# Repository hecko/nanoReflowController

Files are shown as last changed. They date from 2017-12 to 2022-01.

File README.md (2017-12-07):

Reflow Oven Controller
====================

**News**

* Forked from 0xPIT & uploaded the code after a lot of restructuration
* Board design has also changed

**Arduino-based reflow oven controller with:**
* [PID] loop control
* [Wave Packet] control for AC output
* graphic TFT LC-Display, drawing the temperature curves
  * using a 5v compatible 1.8" of 1.44" TFT SPI display with ST7735 controller
* solely controlled using a cheap rotary encoder and its single button
* uses a MAX6675 module as interface to a K type thermocouple
* stores up to 30 temperature profiles in EEPROM
* configurable PID-parameters
* simple, small hardware to drive loads up to 600V and up to 2A without heatsink
* powered throuhg one of three options: 12v RAW pin, 5v pin or 5v USB
* optional 12v fan control (not yet implemented in the code)
* *Please Note*: Requires Arduino IDE 1.5.x or newer

(c) 2017 David Sanz Kirbis
(c) 2014 Karl Pitrich <karl@pitrich.com>
in part based on a project (c) 2013 Ed Simmons <ed@estechnical.co.uk>

## Warning: This project operates with possibly lethal mains voltage. If you are unsure what to do, don't do it and get help from an experienced tinkerer with professional training.

**Minimal build**

BoardPic1 | BoardPic2
------------ | -------------

**Completely populated**

Complete1 | Complete2 | Complete3
------------ | ------------ | -------------

**Enclosed and mounted on halogen floodlight**

(more info: [Halogen Floodlight SMT reflow])

Floodlight
--------------

<!---
**Post action shot**

![CycleWithOverflow] | ![Warning]
------------ | -------------

Introduction
====================

This Reflow Oven Controller relies on an [Arduino Nano] easily obtainable on eb*y for less than $10, plus my custom shield, which is actually more like a motherboard.

As I believe it is not wise to have a mess of wiring and tiny breakout-boards for operating mains powered equipment, I've decided to design custom board with easily obtainable components.

The hardware can be found in the [folder hardware], including the Eagle schematics and PCB layout files. It should fit the freemium version of Eagle. Here are preview images:

![PCB][ImgPCB]
![Schematic][ImgSCH]

The board contains the [Arduino Nano], very simple [Zero crossing] detection circuit, used to align control logic to mains frequency, two [MAX31855] thermocouple-to-digital converters and two [Sharp S202S01] PCB-mount solid state relays, mounted on cheap [Fischer SK409 50,8] heat sinks. The current software uses only one of the thermocouples, so you need to populate one IC only. If you're lucky, you can get free samples of the MAX31855 from Maxim.

The software uses [PID] control of the heater and fan output for improved temperature stability. The heater AC load is controlled using [Wave Packet] control in order to minimize RF interference and load on the relay. For the fan motor, [Phase Fired] control has been implemented.

Please note that all important timings are *based on the mains frequency*, so the circuit will **not work** properly without mains connection.

But for testing, I've added an additional timer to simulate the zero-crossings, in order to run the software without being connected to mains. The software should work in 50 and 60Hz mains, the 60Hz version is not tested, though.

Errata and construction infos
========

Issue | Notes
------------ | -------------

Screenshots and usage information
========

Image | Information
------------ | -------------
![CycleWithOverflow] | *Display after a cylcle has been completed. The blue line is the setpoint, the red line the actual temperature measured by the thermocouple. Note that the graph wraps around automatically. 'Sp' is the current setpoint calculated by the PID loop. In the lower line there are: Current heater and fan outputs, both in percent, and the current temperature rise or drop rate in °C per second. The graph will draw orientation lines every 50°C up to the peak temperature set in the selected profile.*
![MenuDefault] | *The main menu can be navigated by rotating the encoder (sic!). Clicking enters the menu item, or navigates to the submenu. Doubleclick moves up or back or exits the menu item.*
![FanSpeedEdit] | *To edit a setting, click once to enter edit mode (red cursor), then rotate to change the value, click again to save. Doubleclick will exit without saving.*
![MenuEditProfile] | -
![ProfileSettings] | *Typical solder profile settings...*
![ProfileSettingsEdit] | *These parameters can be easily edited using the encoder as described above.*
![MenuLoadProfile] | *Up to 30 Profiles can be loaded and saved. You have to do this manually, so that you can have 'save-as' functionality without overwriting existing profiles.*
![PIDValues] | *Current pid values for my 1300W 20$ toaster oven.*
![PIDValuesEdit] | *Editing is simple, like above. Note that, unlike with the profile settings, the PID values will be automatically stored to EEPROM when you exit the submenu by doubleclicking.*
--->

Obtaining the source code
====================

Get the code using `git`.

	git clone https://github.com/hecko/nanoReflowController.git

or [download a Snapshot].

I've added some libraries I've used as submodules to the git repositroy, so it is important that, after cloning this repository, you do 

    git submodule update --init

to fetch all involved libraries. (See: [Submodule Cheat Sheet])

Installation
====================

Of course, you need to have the Arduino IDE installed. I've worked with version 1.5.x only and I will not support older versions. Get it from the [Arduino Download] page or upgrade you current Arduino setup.

There as several dependencies you need to install. 

If you are unfamiliar with Arduino Libraries, please read [the library guide].
Basically, each library needs to be liked or copied into your Arduino library folder.

<!---
My code uses [TimerOne] for basic timing, for the 1.8" TFT I've used [Adafruit_ST7735], which requires [Adafruit_GFX]. I **strongly suggest** to use my **modified version** of [Adafruit_ST7735-pit], as it **performs much better**, but requires you to use SPI, which my board does anyway.

For the user interface you require my own [Menu] and [ClickEncoder] libraries, which are included as submodules.

All other libraries need to be downloaded and installed.

After you've installed all libraries, open the Arduino IDE, open the ReflowController.pde sketch (using File->Open).

Select the right hardware from the Tools->Board menu.

Compile the firmware (Sketch->Verify) to test everything is installed correctly. If something's wrong, feel free to post an issue here on github, I will look into it.

Now, choose the correct serial port from Tools->Serial Port and then upload the code.
*Remember* that a standard compile will get stuck at "Calibrating..." without proper mains connection, so that zero crossing interrupts can occur.

I could not fit PID Autotuning into the limited space of the Arduino in addition the normal code. So if you want to try to autotune you PID Loop, install the [PID_AutoTune] Library, `#define PIDTUNE 1` in the .ino file, then recompile and download do the Arduino.

As all timing relies on Zero Crossing detection, you need to `#define FAKE_HW 1` and install [TimerThree] when you want to run without actual hardware *and/or* without mains connection.

Things to note
====================

* The [MAX31855] does not like the thermocouple being grounded; It must be isolated from ground or earth.
* The PID Loop must be tuned individually for each oven. It will *not* work out of the box. 
* [PID Autotune] is not very useful, as it seems to be able to tune only to keep a specific temperature value, which is not what we do in a reflow oven. Also, at least my oven seems to be very non-linear when heating up.
* When rewiring inside your oven, use only wiring that can withstand high temperatures. I use silicone coated lace.
* Do not solder wiring inside you oven, the temperature might desolder you joints. **Crimp everything.**
* Use proper earth ground connection for your ovens chassis.

Ideas and todo
====================
* Optimize code size so that more features can fit
* Clamp values for parameters to reasonalbe ranges
* Add scrollbar (sample implementation in the demo for [Menu]
* Separate PID configuration for each process step
* try to make the display faster, it is very slow
* Named profiles
* Rewrite [Menu] so that is uses callback objects instead of spaghetti-callbacks
--->

Licensing
====================
```
The MIT License (MIT)

Copyright (c) 2017 David Sanz Kirbis
All rights reserved.

Permission is hereby granted, free of charge, to any person obtaining a copy
of this software and associated documentation files (the "Software"), to deal
in the Software without restriction, including without limitation the rights
to use, copy, modify, merge, publish, distribute, sublicense, and/or sell
copies of the Software, and to permit persons to whom the Software is
furnished to do so, subject to the following conditions:

The above copyright notice and this permission notice shall be included in
all copies or substantial portions of the Software.

THE SOFTWARE IS PROVIDED "AS IS", WITHOUT WARRANTY OF ANY KIND, EXPRESS OR
IMPLIED, INCLUDING BUT NOT LIMITED TO THE WARRANTIES OF MERCHANTABILITY,
FITNESS FOR A PARTICULAR PURPOSE AND NONINFRINGEMENT. IN NO EVENT SHALL THE
AUTHORS OR COPYRIGHT HOLDERS BE LIABLE FOR ANY CLAIM, DAMAGES OR OTHER
LIABILITY, WHETHER IN AN ACTION OF CONTRACT, TORT OR OTHERWISE, ARISING FROM,
OUT OF OR IN CONNECTION WITH THE SOFTWARE OR THE USE OR OTHER DEALINGS IN
THE SOFTWARE.
```

[PID Autotune]:https://github.com/br3ttb/Arduino-PID-AutoTune-Library
[Submodule Cheat Sheet]:http://blog.jacius.info/git-submodule-cheat-sheet/
[ESTechnical]:http://www.estechnical.co.uk
[Arduino Download]:http://arduino.cc/en/Main/Software
[folder hardware]:https://github.com/dasaki/nanoReflowController/tree/master/hardware
[download a Snapshot]:https://github.com/dasaki/nanoReflowController/archive/master.zip
[the library guide]:http://arduino.cc/en/Guide/Libraries
[PID]:http://en.wikipedia.org/wiki/PID_controller
[Wave Packet]:http://de.wikipedia.org/wiki/Schwingungspaketsteuerung
[Phase Fired]:http://en.wikipedia.org/wiki/Phase-fired_controllers 
[Adafruit 1.8" TFT]:http://www.adafruit.com/products/358
[MAX31855]:http://www.maximintegrated.com/en/products/analog/sensors-and-sensor-interface/MAX31855.html
[Fischer SK409 50,8]:http://www.pollin.de/shop/dt/NzE5OTY1OTk-
[Sharp S202S01]:http://sharp-world.com/products/device/lineup/data/pdf/datasheet/s102s01_e.pdf
[Zero crossing]:http://en.wikipedia.org/wiki/Zero_crossing
[TimerOne]:http://playground.arduino.cc/Code/Timer1
[TimerThree]:http://playground.arduino.cc/Code/Timer1
[Adafruit_ST7735]:https://github.com/adafruit/Adafruit-ST7735-Library
[Adafruit_GFX]:https://github.com/adafruit/Adafruit-GFX-Library
[Adafruit_ST7735-pit]:https://github.com/0xPIT/Adafruit-ST7735-Library
[Menu]:https://github.com/0xPIT/menu
[ClickEncoder]:https://github.com/0xPIT/encoder
[Arduino Nano]:https://store.arduino.cc/arduino-nano

[CycleWithOverflow]:https://raw.githubusercontent.com/0xPIT/reflowOvenController/master/images/CycleWithOverflow.jpg
[FanSpeedEdit]:https://raw.githubusercontent.com/0xPIT/reflowOvenController/master/images/FanSpeedEdit.jpg
[MenuDefault]:https://raw.githubusercontent.com/0xPIT/reflowOvenController/master/images/Menu.jpg
[MenuLoadProfile]:https://raw.githubusercontent.com/0xPIT/reflowOvenController/master/images/MenuLoadProfile.jpg
[MenuEditProfile]:https://raw.githubusercontent.com/0xPIT/reflowOvenController/master/images/MenuEditProfile.jpg
[PIDValuesEdit]:https://raw.githubusercontent.com/0xPIT/reflowOvenController/master/images/PIDValuesEdit.jpg
[ProfileSettings]:https://raw.githubusercontent.com/0xPIT/reflowOvenController/master/images/ProfileSettings.jpg
[PIDValues]:https://raw.githubusercontent.com/0xPIT/reflowOvenController/master/images/PIDValues.jpg
[ProfileSettingsEdit]:https://raw.githubusercontent.com/0xPIT/reflowOvenController/master/images/ProfileSettingsEdit.jpg

[Warning]:http://www.proshieldsafetysigns.co.uk/signs/59793_signs.jpg
[ImgPCB]:https://raw.githubusercontent.com/0xPIT/reflowOvenController/master/hardware/v0.2.brd.preview.png
[ImgSCH]:https://raw.githubusercontent.com/0xPIT/reflowOvenController/master/hardware/v0.2.sch.preview.png

[ImgMissingTrace]:https://raw.githubusercontent.com/0xPIT/reflowOvenController/master/images/MissingTrace.jpg
[BoardPic1]:https://raw.githubusercontent.com/dasaki/nanoReflowController/master/images/v1_0_Board_picture_top.jpg
[BoardPic2]:https://raw.githubusercontent.com/dasaki/nanoReflowController/master/images/v1_0_Board_picture_bottom.jpg
[Complete1]:https://raw.githubusercontent.com/dasaki/nanoReflowController/master/images/v1_0_Board_3d_01.png
[Complete2]:https://raw.githubusercontent.com/dasaki/nanoReflowController/master/images/v1_0_Board_3d_02.png
[Complete3]:https://raw.githubusercontent.com/dasaki/nanoReflowController/master/images/v1_0_Board_3d_03.png
[Floodlight]:https://raw.githubusercontent.com/dasaki/nanoReflowController/master/images/v1_0_floodlight_reflow.jpg
[Halogen Floodlight SMT reflow]:http://therandomlab.blogspot.com.es/2017/07/halogen-floodlight-smt-reflow.html

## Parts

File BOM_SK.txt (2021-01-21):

Reflektor:
  * https://www.hagard.sk/katalog-produktov/svietidla-zdroje-objimky-transformatory-1/svietidla-reflektory/reflektor-halogenovy-6107-500w-r7s-118mm-230v-ip44-cierna.html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 / EAN: 8590849061079 / Ecoplanet / Hagard kod: SRE000000154

Kapton paska:
  * P3D0107PT / elecrow

Alobal

6mm (vonkajsi priemer / 4mm vnutorny) teflonova trubka
  * gumex.sk / 0165060000000209
  * http://www.sterimob.sk/e-4241-ptfe-trubka-teflon-64mm
  * SOS: 26386

Elektronicke komponenty:
  * poistka: 1271687 / farnell
  * encoder: SMEC11EN / elecrow
  * display: https://techfun.sk/produkt/segmentovy-display-tm1637
  * K-type thermocouple: SPM28130K / elecrow / https://techfun.sk/produkt/k-type-termoclanok-kabel-1-meter/
  * Arduino Nano klon: MCA03328A / elecrow

Vyroba dosiek: Elecrow / SPF11010S

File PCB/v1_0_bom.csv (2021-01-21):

DESIGNATORS | VALUE | VALUE_NOTE | VALUE_EX | LIBREF | FOOTPRINT | FARNELL | SOS | MOUSER | TME | DIGIKEY | FILEPATH
ARDUINO_NANO_(5V)1 | arduino_nano_header |  |  | arduino-headers:arduino_nano_header | Module:Arduino_Nano |  |  |  |  |  | ./nanoReflow_v1.0_rev3//arduino_nano_reflow_TRIAC_v1_0.sch
C2 C3 | 100n |  |  | Device:C | Capacitor_SMD:C_0805_2012Metric |  |  |  |  |  | ./nanoReflow_v1.0_rev3//arduino_nano_reflow_TRIAC_v1_0.sch
R2 R1 | 47k 0.6w |  |  | Device:R | Resistor_THT:R_Axial_DIN0207_L6.3mm_D2.5mm_P7.62mm_Horizontal |  |  |  |  |  | ./nanoReflow_v1.0_rev3//arduino_nano_reflow_TRIAC_v1_0.sch
R7 | 100K |  |  | Device:R | Resistor_SMD:R_1210_3225Metric |  |  |  |  |  | ./nanoReflow_v1.0_rev3//arduino_nano_reflow_TRIAC_v1_0.sch
J2 | HEATER |  |  | arduino_nano_reflow_TRIAC_v1_0-rescue:Screw_Terminal_1x02 | TerminalBlock_Phoenix:TerminalBlock_Phoenix_MKDS-1;5-2_1x02_P5.00mm_Horizontal |  |  |  |  |  | ./nanoReflow_v1.0_rev3//arduino_nano_reflow_TRIAC_v1_0.sch
J3 | DC IN 12V |  |  | arduino_nano_reflow_TRIAC_v1_0-rescue:Screw_Terminal_1x02 | TerminalBlock_Phoenix:TerminalBlock_Phoenix_MKDS-1;5-2_1x02_P5.00mm_Horizontal |  |  |  |  |  | ./nanoReflow_v1.0_rev3//arduino_nano_reflow_TRIAC_v1_0.sch
J1 | AC IN 220v |  |  | arduino_nano_reflow_TRIAC_v1_0-rescue:Screw_Terminal_1x02 | TerminalBlock_Phoenix:TerminalBlock_Phoenix_MKDS-1;5-2_1x02_P5.00mm_Horizontal |  |  |  |  |  | ./nanoReflow_v1.0_rev3//arduino_nano_reflow_TRIAC_v1_0.sch
Q1 | IRF540N |  |  | Transistor_FET:IRF540N | Package_TO_SOT_THT:TO-220-3_Vertical |  |  |  |  |  | ./nanoReflow_v1.0_rev3//arduino_nano_reflow_TRIAC_v1_0.sch
D1 | 1N4007 |  |  | Device:D_Small | Diode_THT:D_A-405_P5.08mm_Vertical_AnodeUp |  |  |  |  |  | ./nanoReflow_v1.0_rev3//arduino_nano_reflow_TRIAC_v1_0.sch
J9 | MAX6675 |  |  | Connector_Generic:Conn_01x05 | Connector_PinHeader_2.54mm:PinHeader_1x05_P2.54mm_Vertical |  |  |  |  |  | ./nanoReflow_v1.0_rev3//arduino_nano_reflow_TRIAC_v1_0.sch
BZ1 | Buzzer with generator |  |  | Device:Buzzer | Buzzer_Beeper:Buzzer_12x9.5RM7.6 |  |  |  |  |  | ./nanoReflow_v1.0_rev3//arduino_nano_reflow_TRIAC_v1_0.sch
R6 | 4K7 |  |  | Device:R | Resistor_SMD:R_1210_3225Metric |  |  |  |  |  | ./nanoReflow_v1.0_rev3//arduino_nano_reflow_TRIAC_v1_0.sch
JP1 | VIN enabler |  |  | Jumper:Jumper_2_Open | Pin_Headers:Pin_Header_Straight_1x02_Pitch2.54mm |  |  |  |  |  | ./nanoReflow_v1.0_rev3//arduino_nano_reflow_TRIAC_v1_0.sch
R5 | 1k |  |  | Device:R | Resistor_SMD:R_0603_1608Metric |  |  |  |  |  | ./nanoReflow_v1.0_rev3//arduino_nano_reflow_TRIAC_v1_0.sch
R3 | 2.4k |  |  | Device:R | Resistor_THT:R_Axial_DIN0207_L6.3mm_D2.5mm_P7.62mm_Horizontal |  |  |  |  |  | ./nanoReflow_v1.0_rev3//arduino_nano_reflow_TRIAC_v1_0.sch
J12 J13 J14 | MOUNTING_HOLE |  |  | arduino_nano_reflow_TRIAC_v1_0-rescue:CONN_01X01 | MountingHole:MountingHole_3.2mm_M3_Pad |  |  |  |  |  | ./nanoReflow_v1.0_rev3//arduino_nano_reflow_TRIAC_v1_0.sch
U1 | MOC3020M |  |  | Relay_SolidState:MOC3020M | Package_DIP:DIP-6_W7.62mm |  |  |  |  |  | ./nanoReflow_v1.0_rev3//arduino_nano_reflow_TRIAC_v1_0.sch
R4 | 180R |  |  | Device:R | Resistor_THT:R_Axial_DIN0207_L6.3mm_D2.5mm_P7.62mm_Horizontal |  |  |  |  |  | ./nanoReflow_v1.0_rev3//arduino_nano_reflow_TRIAC_v1_0.sch
C1 | 10n |  |  | Device:C | Capacitor_THT:C_Disc_D4.3mm_W1.9mm_P5.00mm |  |  |  |  |  | ./nanoReflow_v1.0_rev3//arduino_nano_reflow_TRIAC_v1_0.sch
J11 | CONN_01X03 |  |  | arduino_nano_reflow_TRIAC_v1_0-rescue:CONN_01X03 | Pin_Headers:Pin_Header_Straight_1x03_Pitch2.54mm |  |  |  |  |  | ./nanoReflow_v1.0_rev3//arduino_nano_reflow_TRIAC_v1_0.sch
KK1 | TRIAC HEATSINK |  |  | SK_09_20_SA_TO_220:SK_09_20_SA_TO_220 | local_libraries:TO_220_heatsink |  |  |  |  |  | ./nanoReflow_v1.0_rev3//arduino_nano_reflow_TRIAC_v1_0.sch
OK1 | H11AA1 |  |  | Isolator:H11AA1 | Package_DIP:DIP-6_W7.62mm |  |  |  |  |  | ./nanoReflow_v1.0_rev3//arduino_nano_reflow_TRIAC_v1_0.sch
TRIAC1 | BT137 |  |  | Device:Q_TRIAC_A1A2G | Package_TO_SOT_THT:TO-220-3_Vertical |  |  |  |  |  | ./nanoReflow_v1.0_rev3//arduino_nano_reflow_TRIAC_v1_0.sch
F1 | Fuse |  |  | Device:Fuse | Fuse_Holders_and_Fuses:Fuseholder5x20_horiz_open_inline_Type-I |  |  |  |  |  | ./nanoReflow_v1.0_rev3//arduino_nano_reflow_TRIAC_v1_0.sch
J4 | 12V FAN |  |  | arduino_nano_reflow_TRIAC_v1_0-rescue:Screw_Terminal_1x02 | TerminalBlock_Phoenix:TerminalBlock_Phoenix_MKDS-1;5-2_1x02_P5.00mm_Horizontal |  |  |  |  |  | ./nanoReflow_v1.0_rev3//arduino_nano_reflow_TRIAC_v1_0.sch
J5 | CONN_01X04 |  |  | Connector_Generic:Conn_01x04 | Connector_PinHeader_2.54mm:PinHeader_1x04_P2.54mm_Vertical |  |  |  |  |  | ./nanoReflow_v1.0_rev3//arduino_nano_reflow_TRIAC_v1_0.sch
J6 | K-thermocouple |  |  | arduino_nano_reflow_TRIAC_v1_0-rescue:Screw_Terminal_1x02 | TerminalBlock_Phoenix:TerminalBlock_Phoenix_MKDS-1;5-2_1x02_P5.00mm_Horizontal |  |  |  |  |  | ./nanoReflow_v1.0_rev3//arduino_nano_reflow_TRIAC_v1_0.sch
U2 | MAX6675 |  |  | max6675:MAX6675 | Package_SO:SO-8_3.9x4.9mm_P1.27mm |  |  |  |  |  | ./nanoReflow_v1.0_rev3//arduino_nano_reflow_TRIAC_v1_0.sch

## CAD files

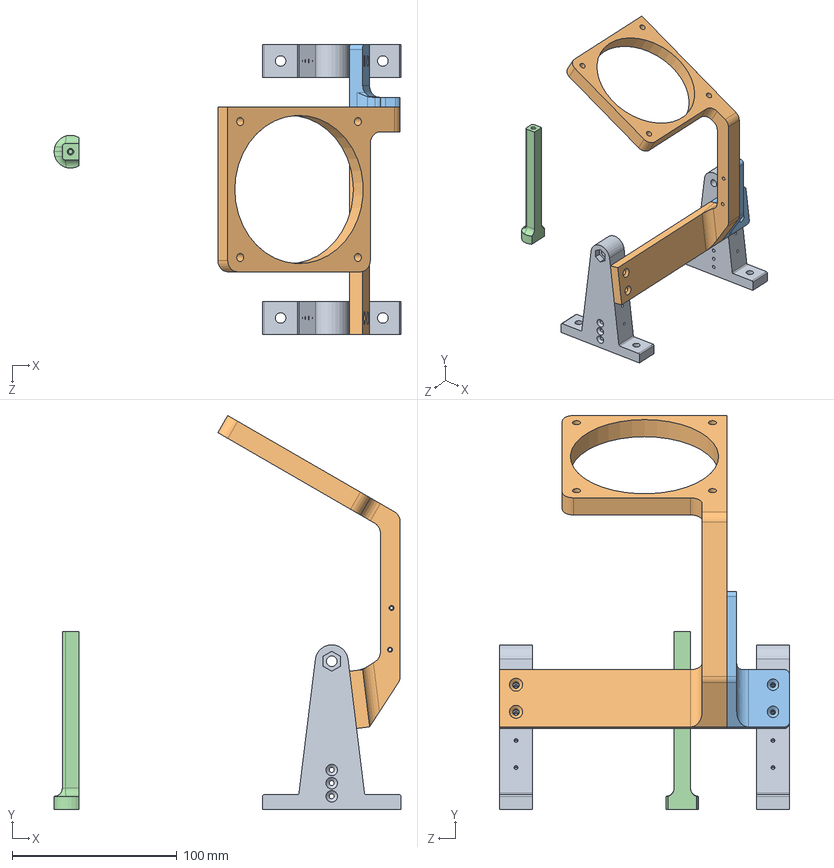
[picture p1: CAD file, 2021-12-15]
CAD/zostava_halogenka.SLDASM
210.6 x 239.2 x 176.0 mm
noha x 2
podpora_pred

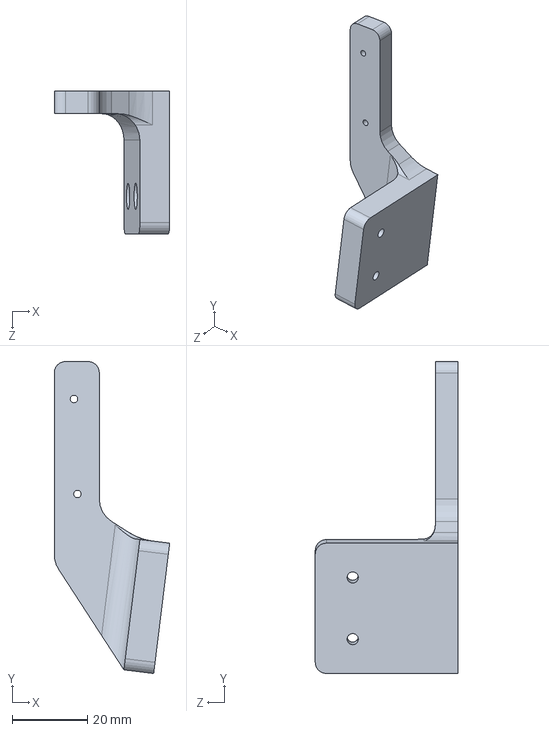
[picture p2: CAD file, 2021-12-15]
CAD/Part2.sldprt
30.8 x 83.1 x 38.0 mm

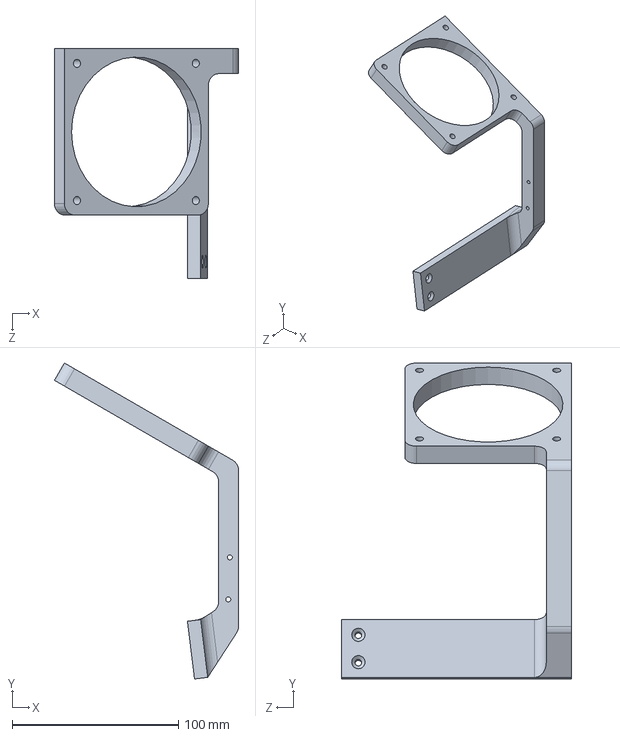
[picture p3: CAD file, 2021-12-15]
CAD/Part1.sldprt
110.7 x 190.0 x 138.0 mm

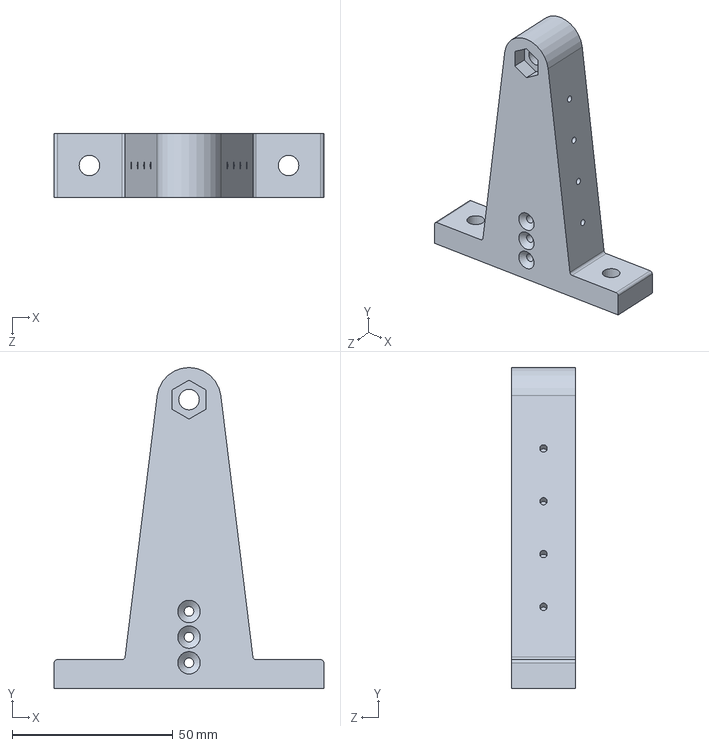
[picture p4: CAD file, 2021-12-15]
CAD/noha.SLDPRT
84.0 x 100.0 x 20.0 mm

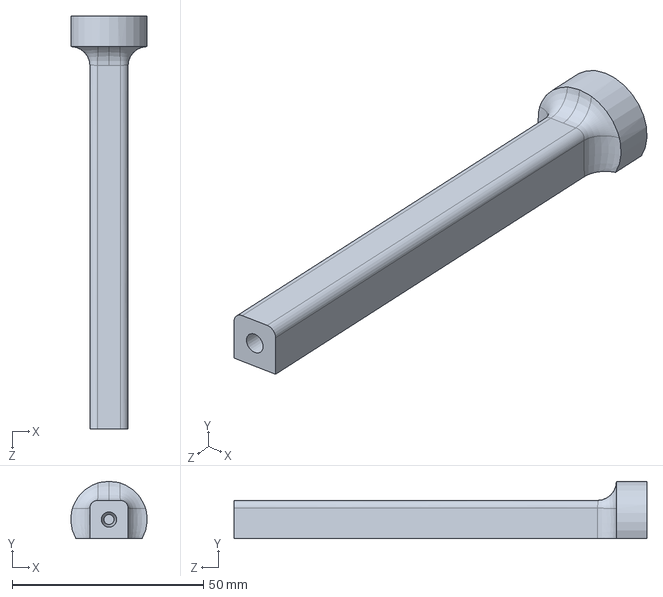
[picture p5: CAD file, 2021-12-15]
CAD/podpora_pred.SLDPRT
20.0 x 15.0 x 108.0 mm

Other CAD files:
CAD/podpora_pred.STL

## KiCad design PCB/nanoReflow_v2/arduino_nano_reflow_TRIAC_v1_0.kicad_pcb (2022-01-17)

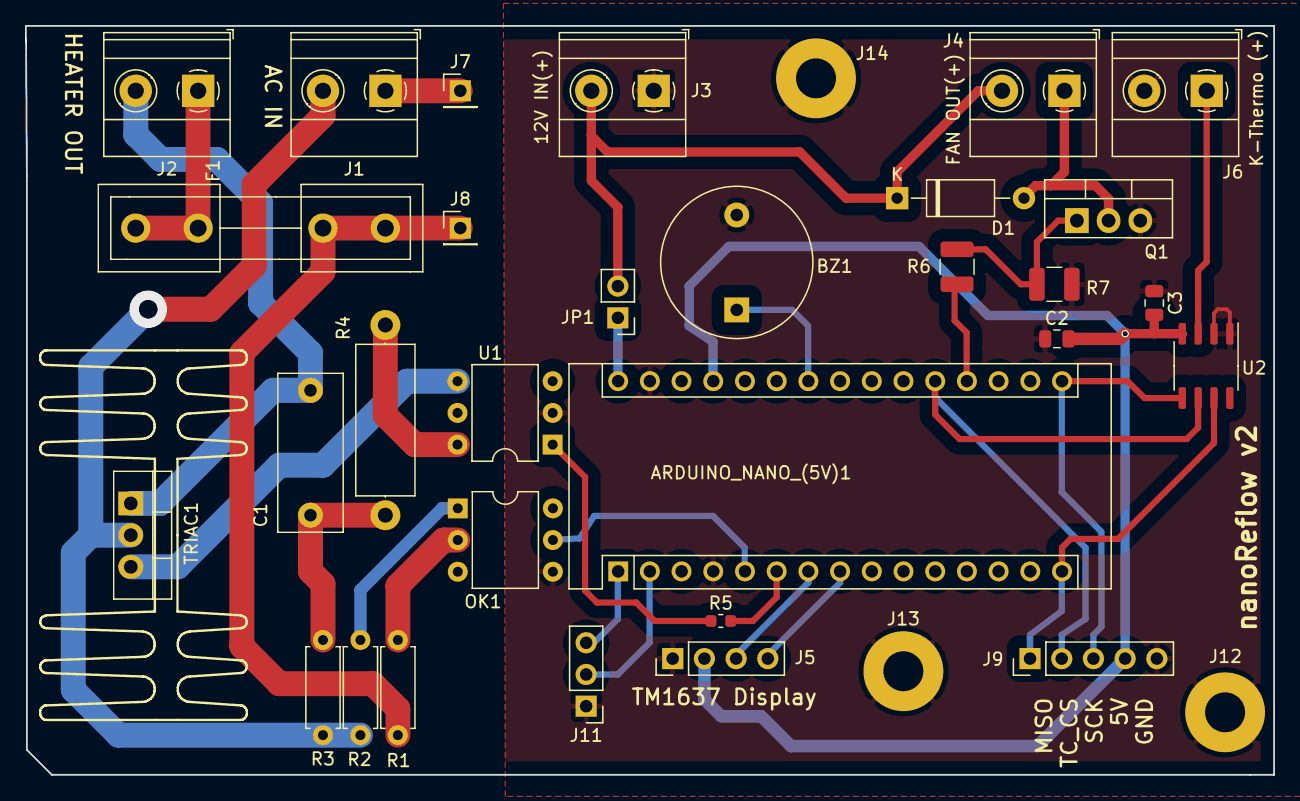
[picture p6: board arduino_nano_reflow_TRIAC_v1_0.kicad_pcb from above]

Board: 2 copper layers, 100.0 x 60.0 mm, 34 parts (0 on the bottom side), 29 nets.

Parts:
ARDUINO_NANO_(5V)1: arduino_nano_header; Arduino_Nano
BZ1: Buzzer with generator; Buzzer_12x9.5RM7.6
C1: 10n; C_Disc_D12.5mm_W5.0mm_P10.00mm
C2, C3: 100n; C_0805_2012Metric
D1: 1N4007; D_A-405_P10.16mm_Horizontal
F1: Fuse; Fuseholder5x20_horiz_open_inline_Type-I
J1: AC IN 220v; TerminalBlock_Phoenix_MKDS-1,5-2_1x02_P5.00mm_Horizontal
J2: HEATER; TerminalBlock_Phoenix_MKDS-1,5-2_1x02_P5.00mm_Horizontal
J3: DC IN 12V; TerminalBlock_Phoenix_MKDS-1,5-2_1x02_P5.00mm_Horizontal
J4: 12V FAN; TerminalBlock_Phoenix_MKDS-1,5-2_1x02_P5.00mm_Horizontal
J5: CONN_01X04; PinHeader_1x04_P2.54mm_Vertical
J6: K-thermocouple; TerminalBlock_Phoenix_MKDS-1,5-2_1x02_P5.00mm_Horizontal
J7: AC2_IN; PinHeader_1x01_P2.54mm_Vertical
J8: AC2_OUT; PinHeader_1x01_P2.54mm_Vertical
J9: MAX6675; PinHeader_1x05_P2.54mm_Vertical
J11: CONN_01X03; Pin_Header_Straight_1x03_Pitch2.54mm
J12, J13, J14: MOUNTING_HOLE; MountingHole_3.2mm_M3_Pad
JP1: VIN enabler; Pin_Header_Straight_1x02_Pitch2.54mm
KK1: TRIAC HEATSINK; TO_220_heatsink
OK1: H11AA1; DIP-6_W7.62mm
Q1: IRF540N; TO-220-3_Vertical
R1, R2: 47k 0.6w; R_Axial_DIN0207_L6.3mm_D2.5mm_P7.62mm_Horizontal
R3: 2.4k; R_Axial_DIN0207_L6.3mm_D2.5mm_P7.62mm_Horizontal
R4: 180R; R_Axial_DIN0414_L11.9mm_D4.5mm_P15.24mm_Horizontal
R5: 1k; R_0603_1608Metric
R6: 4K7; R_1210_3225Metric
R7: 100K; R_1210_3225Metric
TRIAC1: BT137; TO-220-3_Vertical
U1: MOC3020M; DIP-6_W7.62mm
U2: MAX6675; SO-8_3.9x4.9mm_P1.27mm

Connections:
5V: ARDUINO_NANO_(5V)1.27, C2.2, C3.2, J5.2, J9.4, U2.4
12v: D1.1, J3.2, J4.2, JP1.2
/AC_CAP: C1.2, R3.1, R4.1
/BUZZER: ARDUINO_NANO_(5V)1.24, BZ1.1
/DIMM_CTRL: ARDUINO_NANO_(5V)1.6, R5.2
/FAN_CTRL: ARDUINO_NANO_(5V)1.19, R6.1
/FAN_GND: D1.2, J4.1, Q1.2
/MISO: ARDUINO_NANO_(5V)1.15, J9.1, U2.7
/MOC_AC1: R4.2, U1.6
/MOC_AC2: TRIAC1.3, U1.4
/OC1: OK1.1, R2.2
/OC2: OK1.2, R1.2
/SCK: ARDUINO_NANO_(5V)1.16, J9.3, U2.5
/SEGMENT_CLK: ARDUINO_NANO_(5V)1.8, J5.4
/SEGMENT_DIO: ARDUINO_NANO_(5V)1.7, J5.3
/TC_CS: ARDUINO_NANO_(5V)1.20, J9.2, U2.6
/VIN: ARDUINO_NANO_(5V)1.30, JP1.1
/ZEROX: ARDUINO_NANO_(5V)1.5, OK1.5
AC1_IN: J1.2, R2.1, R3.2, TRIAC1.2
AC1_OUT: C1.1, J2.2, TRIAC1.1
AC2_IN: F1.2, J8.1, R1.1
AC2_OUT: F1.1, J2.1
GND: ARDUINO_NANO_(5V)1.4, ARDUINO_NANO_(5V)1.29, BZ1.2, C2.1, C3.1, J3.1, J5.1, J6.2, J9.5, J11.1, J12.1, J13.1, J14.1, OK1.4, Q1.3, R7.1, U1.2, U2.1, U2.2
unnamed: ARDUINO_NANO_(5V)1.1, J11.3
unnamed: ARDUINO_NANO_(5V)1.2, J11.2
unnamed: J1.1, J7.1
unnamed: J6.1, U2.3
unnamed: Q1.1, R6.2, R7.2
unnamed: R5.1, U1.1

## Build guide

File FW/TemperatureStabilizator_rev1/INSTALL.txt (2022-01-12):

use arduino librarby manager to install:
  * https://github.com/avishorp/TM1637 (the one from Avishay Orpaz)
  * PID library from Brett Beauregard
  * max6675 from Adafruit

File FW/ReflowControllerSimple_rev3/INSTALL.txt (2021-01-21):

use arduino librarby manager to install https://github.com/avishorp/TM1637 (the one from Avishay Orpaz)

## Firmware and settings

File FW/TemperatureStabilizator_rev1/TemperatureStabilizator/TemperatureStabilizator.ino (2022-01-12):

#include "max6675.h"
#include <TM1637Display.h>
#include <PID_v1.h>

#define PIN_HEATER 3

#define PIN_LCD_DIO 4
#define PIN_LCD_CLK 5

#define PIN_TC_CS A1
#define PIN_TC_DO 12
#define PIN_TC_CLK 13
#define FAN_PIN A0
#define BUZZER_PIN A5

#define TARGET_TEMP 40

TM1637Display display(PIN_LCD_CLK, PIN_LCD_DIO);
MAX6675 thermocouple(PIN_TC_CLK, PIN_TC_CS, PIN_TC_DO);

double pidSetpoint;
double pidInput = 25;
double pidOutput;
PID myPID(&pidInput, &pidOutput, &pidSetpoint, 2, 5, 1, DIRECT);

double t;

void setup() {
  pinMode(PIN_HEATER, OUTPUT);
  pinMode(FAN_PIN, OUTPUT);
  pinMode(BUZZER_PIN, OUTPUT);

  display.setBrightness(0x0f);
  display.showNumberDec(8888, false);

  tone(BUZZER_PIN, 4000);
  delay(100);
  noTone(BUZZER_PIN);

  digitalWrite(PIN_HEATER, 0);

  Serial.begin(115200);
  Serial.println("begin");

  pidSetpoint = TARGET_TEMP;
  myPID.SetMode(AUTOMATIC);
}

void loop() {
  t = -1;
  t = readThermocouple();
  t = readThermocouple();
  t = readThermocouple();
  if ((t > 260) || (t <= 0)) {
    Serial.println("Kill heater - something wrong with temperature probe!");
    Serial.print("current C: ");
    Serial.println(round(t));
    digitalWrite(PIN_HEATER, LOW);
    while (1) {
      tone(BUZZER_PIN, 4000);
      delay(2000);
      noTone(BUZZER_PIN);
      delay(1000);
    };
  }

  pidInput = t;
  myPID.Compute();

  Serial.print("TARGET_TEMP:");
  Serial.print(TARGET_TEMP);
  Serial.print(";");
  Serial.print("CURRENT_TEMP:");
  Serial.print(t);
  Serial.print(";");
  Serial.print("PID_OUTPUT:");
  Serial.print(pidOutput);
  Serial.print(";");
  Serial.println();

  display.clear();
  display.showNumberDec(t, false);

  analogWrite(PIN_HEATER, pidOutput);
  delay(50); // ak tu toto nie je senzor vracia stale tu istu hodnotu!
}

void fan_on() {
  Serial.println("Turning FAN ON!");
  analogWrite(FAN_PIN, 255);
}

void fan_off() {
  Serial.println("Turning FAN OFF!");
  analogWrite(FAN_PIN, 0);
}

float readThermocouple() {
  digitalWrite(PIN_TC_CS, LOW);
  delay(300); // otherwise does not work!!
  float temperature = thermocouple.readCelsius();
  delay(300); // otherwise does not work!!

  if (temperature == NAN) {
    Serial.println("Unable to read temperature!");
    temperature = -100;
  }

  digitalWrite(PIN_TC_CS, HIGH);
  return temperature;
}

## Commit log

2017-11-13 added part list and sources for pelectronic parts
    [v1_0_bom.csv]
2017-11-14 mode parts from farnell
    [v1_0_bom.csv]
2017-11-14 added gerbers that have been sent to elecrow
2017-11-14 updated bom-sk
2017-11-14 clarification BOM
2017-12-03 added r1, r2 resistors farnell reference
    [v1_0_bom.csv]
2017-12-03 headed update to prettify
    [v1_0_bom.csv]
2019-12-29 unpack kicad files
    [arduino_nano_reflow_TRIAC_v1_0.kicad_pcb, arduino_nano_reflow_TRIAC_v1_0.sch]
2019-12-29 upgrade to kicad 5.1.5
    [arduino_nano_reflow_TRIAC_v1_0-2019-12-29-02-04-57.sch]
2020-05-22 - new revision of board - suitable for production with oshpark - updated footprints - cross checked with original schematics
    [arduino_nano_reflow_TRIAC_v1_0-B_Adhes.gbr, arduino_nano_reflow_TRIAC_v1_0-B_Cu.gbr, arduino_nano_reflow_TRIAC_v1_0-B_Mask.gbr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]
2020-05-22 added fundamentally trivial script to test the heater - just keeps resired tenperature forever, no profiles, nothing
2020-05-22 update footprint to match kicad 5.1.6 - SIP suitable for oshpark
    [arduino_nano_reflow_TRIAC_v1_0-B_Adhes.gbr, arduino_nano_reflow_TRIAC_v1_0-B_Cu.gbr, arduino_nano_reflow_TRIAC_v1_0-B_Mask.gbr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]
2020-05-25 pid as module
2020-09-16 add beeping when temperature <150
2020-09-17 add cad files for 3d printing
    [Part1.sldprt, Part2.sldprt, noha.SLDPRT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]
2020-09-17 updated PCB to v1.0_rev3 - more space for connectors and rewired for better access to FAN port
    [arduino_nano_reflow_TRIAC_v1_0-B_Adhes.gbr, arduino_nano_reflow_TRIAC_v1_0-B_Cu.gbr, arduino_nano_reflow_TRIAC_v1_0-B_Mask.gbr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]
2020-09-17 remove gerbers zip file
2020-09-17 add missing heatsink footprint
    [arduino_nano_reflow_TRIAC_v1_0.kicad_pcb, arduino_nano_reflow_TRIAC_v1_0.sch]
2021-01-08 update - make sure to not turn anything on when temperature == 0
2021-01-21 update - poslane do vyroby
    [arduino_nano_reflow_TRIAC_v1_0-B_Adhes.gbr, arduino_nano_reflow_TRIAC_v1_0-B_Cu.gbr, arduino_nano_reflow_TRIAC_v1_0-B_Mask.gbr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]
2021-02-19 add firmware for new pcb
2021-12-15 update cad
    [Part1.sldprt, Part2.sldprt, noha.SLDPRT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]
2022-01-17 presun ac suciastok tak aby bolo viac miesta + zmena footprintov pre vykonove suciastky
    [arduino_nano_reflow_TRIAC_v1_0-2019-12-29-02-04-57.sch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]
